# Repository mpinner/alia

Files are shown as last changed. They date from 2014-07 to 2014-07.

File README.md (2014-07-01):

alia
====

Alia: Bringing back human connection (2nd place winner of #ExtremeWearables designathon)

￼￼alia sharing accountability
Mary, Ella, Jon, M, Matt, Divya
￼A pair of socially connected devices
￼‘buddy’
￼Performs interventions to overcome digital addiction
￼￼￼￼￼thinking of having a conversation
￼￼￼
￼Context: Digital Dependency
3 states of being
￼￼￼PLUGGED
UNPLUGGED
ASLEEP
There is tendency of being constantly plugged in.
￼Problem
Addiction to devices (plugged state) is socially acceptable.
Constant connectivity demands an escape i.e a state of being unplugged
Disconnect to physical world affects mental and physical health, personal relationships
￼￼Buddy System
Being accountable to another person is effective in breaking a bad habit
￼￼
alia
￼￼
How it Works
‘Addict’ & ‘Buddy’ relationship
When limit reached, Buddy alerted
Buddy reminds Addict to take break and unplug
￼Device detect loved one’s ‘state level’
How it Works
‘Addict’ & ‘Buddy’ relationship
Device detect loved one’s ‘state level’
Buddy reminds Addict to take break and unplug
￼When limit reached, Buddy alerted
How it Works
‘Addict’ & ‘Buddy’ relationship
￼Buddy reminds Addict to take break and unplug
Device detect loved one’s ‘state level’
When limit reached, Buddy alerted
￼How it Works
Bring back human connection
Each user acts as the buddy and addict at different points
￼￼￼￼￼￼
￼Controls
Hours Limit
￼￼￼Method of Intervention
In person Intervention Intervention by proxy Gentle nudge Annoying tap Electrical Pulse
Fine (money)
￼￼￼￼￼￼￼￼￼￼￼￼￼￼￼￼Strength of Intervension
Mild Intense
￼￼
￼Relationships
Peer to Peer
Friend to Friend
Long Distance Relationships
Couples
Caretaker to Dependant
Parent to Child, Teacher to Student
Between a group of individuals
Group of Friends, Family
￼How it Works
In Touch
Map loved ones and relationsips being tracked to body
Device acts as a portal to connect loved ones and their ‘states’
￼￼￼￼￼￼￼￼￼￼￼
alia
￼￼

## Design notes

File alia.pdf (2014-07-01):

# alia

## sharing accountability

Mary, Ella, Jon, M, Matt, Divya

# A pair of socially connected devices

thinking of | having a conversation
‘buddy’ | Performs interventions to overcome digital addiction

Context: Digital Dependency

PLUGGED | UNPLUGGED | ASLEEP

# 3 states of being

There is tendency of being constantly plugged in.

Problem

Addiction to devices (plugged state) is socially acceptable.

Constant connectivity demands an escape i.e a state of being unplugged

Disconnect to physical world affects mental and physical health, personal relationships

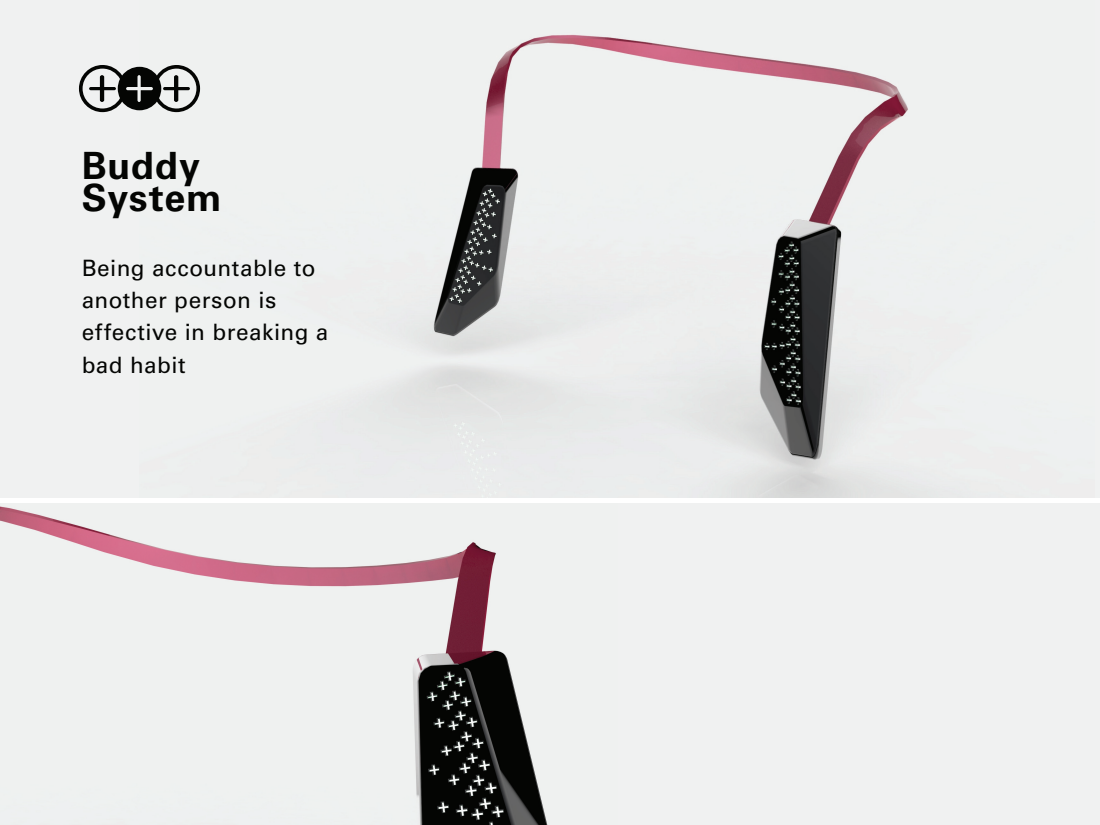
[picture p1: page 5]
Buddy System

Being accountable to
another person is
effective in breaking a
bad habit

# alia

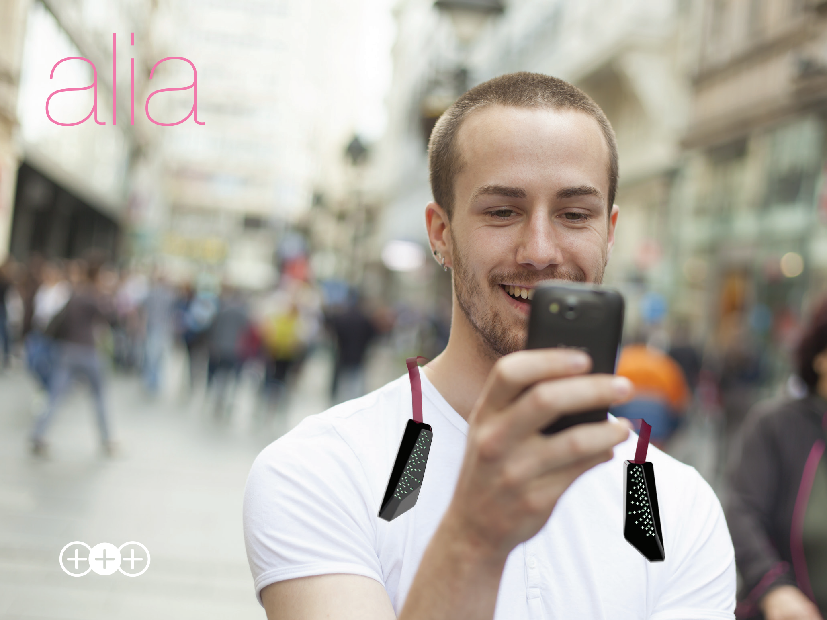
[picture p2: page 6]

# ‘Addict’ & ‘Buddy’ relationship

Device detect
loved one’s
‘state level’

When limit
reached, Buddy
alerted

Buddy reminds
Addict to take
break and
unplug

How it Works

# ‘Addict’ & ‘Buddy’ relationship

Device detect
loved one’s
‘state level’

When limit
reached, Buddy
alerted

Buddy reminds
Addict to take
break and
unplug

How it Works

# ‘Addict’ & ‘Buddy’ relationship

Device detect
loved one’s
‘state level’

When limit
reached, Buddy
alerted

Buddy reminds
Addict to take
break and
unplug

How it Works

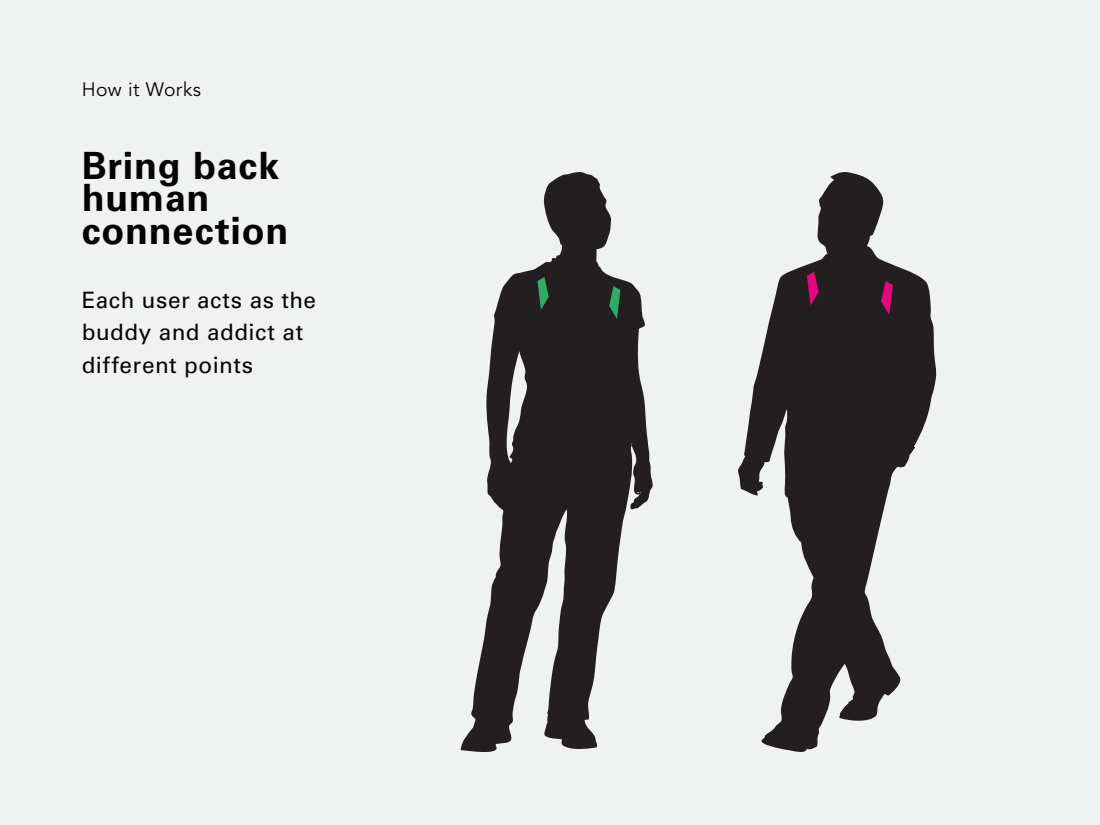
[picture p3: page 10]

How it Works
Bring back
human
connection

Each user acts as the
buddy and addict at
different points

Controls

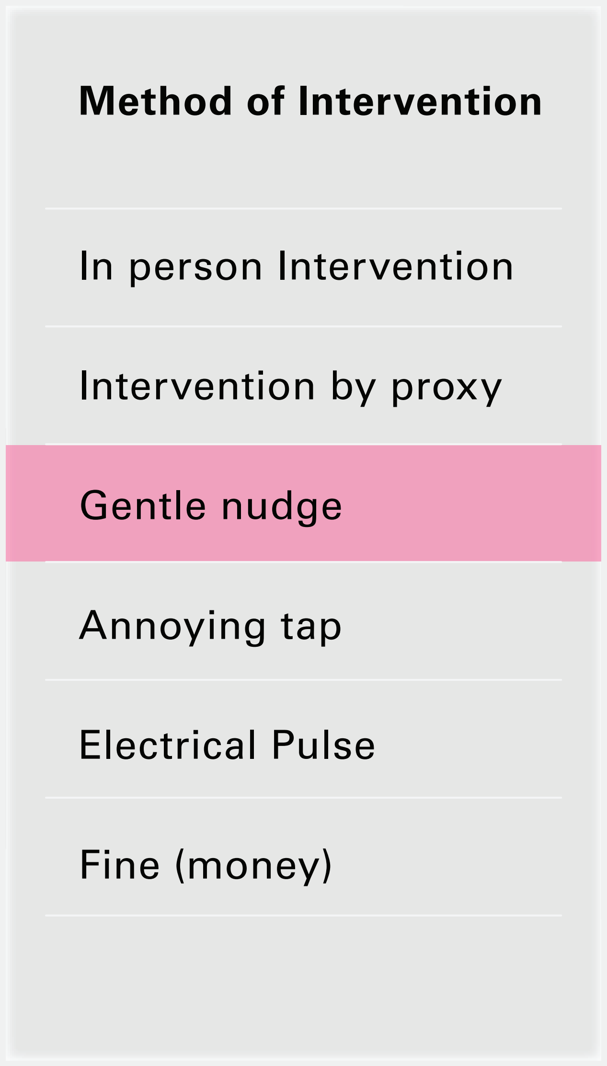
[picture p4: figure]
Method of Intervention; In person Intervention; Intervention by proxy; Gentle nudge; Annoying tap; Electrical Pulse; Fine (money)
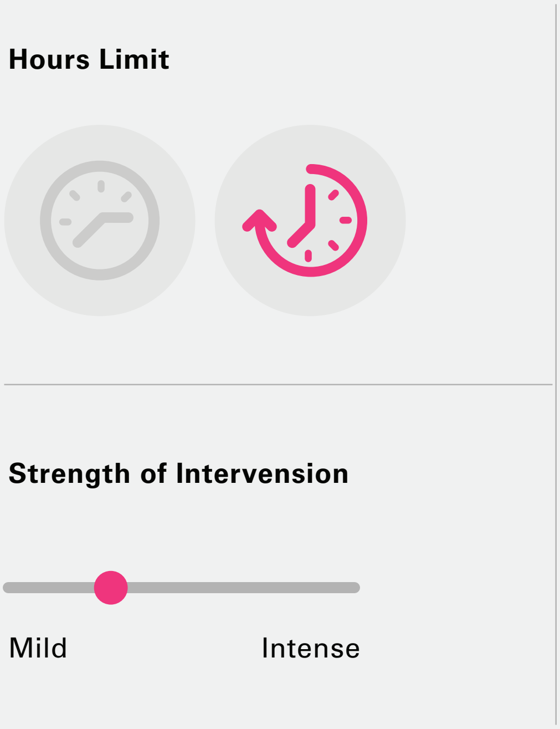
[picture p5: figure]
Hours Limit; Strength of Intervension; Mild; Intense

Relationships

Peer to Peer
Friend to Friend
Long Distance Relationships
Couples
Caretaker to Dependant
Parent to Child, Teacher to Student

Between a group of individuals
Group of Friends, Family

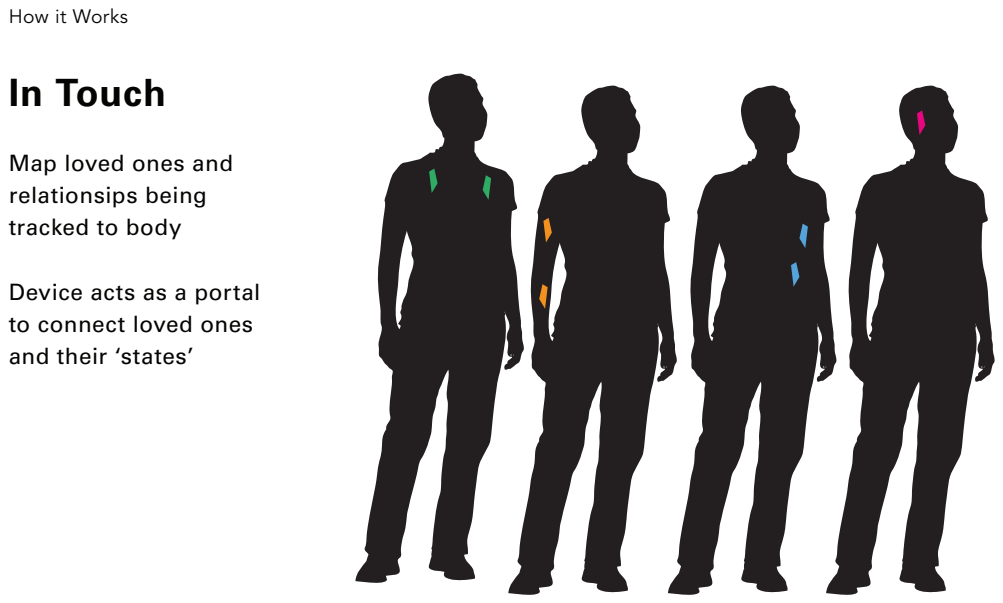
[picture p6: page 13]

How it Works
In Touch

Map loved ones and
relationsips being
tracked to body

Device acts as a portal
to connect loved ones
and their ‘states’

# alia

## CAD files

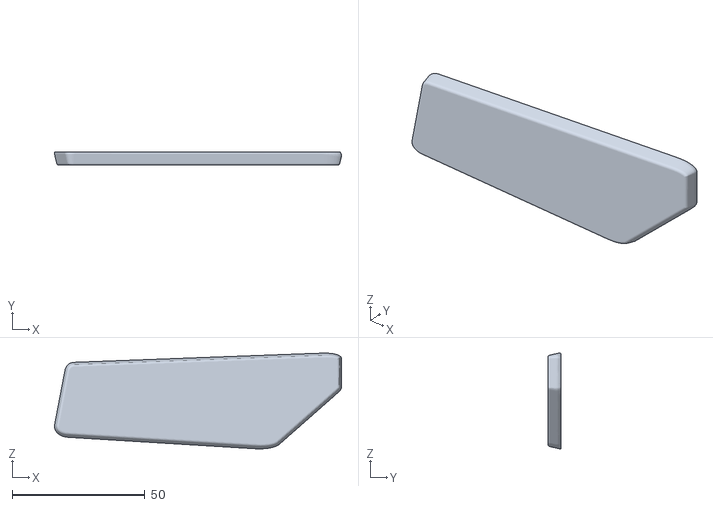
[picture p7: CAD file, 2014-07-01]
models/extreme-wearable-designathon_small-mirrored-bot.STL
108.2 x 5.08 x 36.1

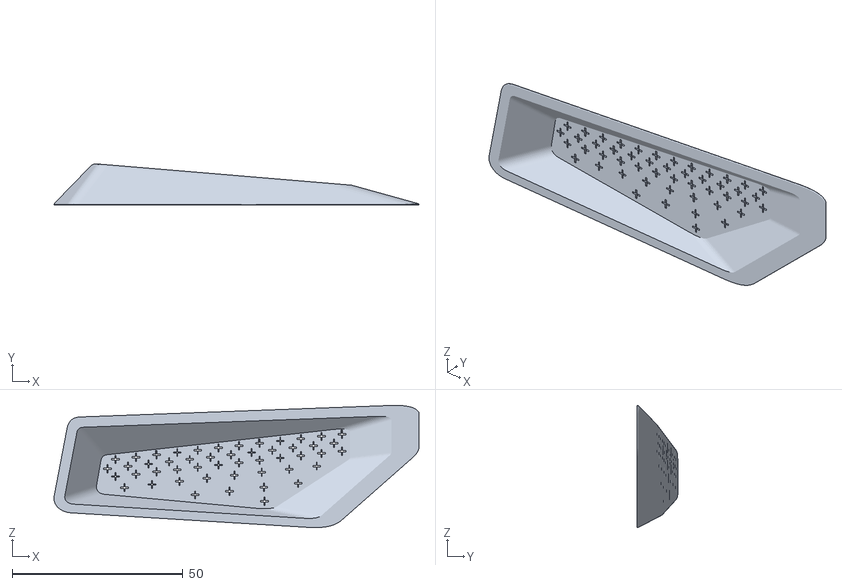
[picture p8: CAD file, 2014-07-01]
models/extreme-wearable-designathon_small-mirrored-top.STL
106.9 x 12.1 x 35.8

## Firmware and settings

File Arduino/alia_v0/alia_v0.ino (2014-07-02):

/* Alia: sharing accountability and bringing back human connection 
 (2nd place winner of #ExtremeWearables designathon)
 Author: matt pinner @mpinner 
 (and team: Ella Jeong, M Asynaps, Jon Hsiung, Mary Kim, Divya Gaitnode)
 
 Intent: connect exactly two people with wearable devices via xbees.
 
 Terms:
 * fuelGauge: shows the sensors readings of the other person's device 
 * emote : recieve a message to the other
 * nudge : send a message to the other
 * sense : read and send local sensors
 * update : send sensor reading
 
 PINS:
 * 0/1 : tx/rx for Serial over XBee 
 * 2   : nudge button (INPUT_PULLUP)
 * 4/5 : adxl345 accelerometer (i2c)
 * 6   : neopixel x8 stick (ws2811)
 * 13  : vibration motor and onboard led (high/low modulated for power savings)
 
 BOM: https://www.sparkfun.com/wish_lists/90529
 * fio: http://arduino.cc/en/Main/ArduinoBoardFio
 * xbee: https://www.sparkfun.com/datasheets/Wireless/Zigbee/XBee-Datasheet.pdf
 * battery: https://www.sparkfun.com/datasheets/Batteries/UnionBattery-1000mAh.pdf 
 * button:https://www.sparkfun.com/datasheets/Components/General/00097.jpg
 * accelerometer: https://www.sparkfun.com/datasheets/Sensors/Accelerometer/ADXL345.pdf
 * leds: https://dlnmh9ip6v2uc.cloudfront.net/datasheets/Components/LED/adafruit-neopixel-uberguide.pdf
 * vibrator: https://www.sparkfun.com/datasheets/Robotics/310-101_datasheet.pdf
 
 PARTS MODELS:
 * fio : https://github.com/sparkfun/3D_Models/tree/master/Products/Prototyping/Arduino%20Fio%20DEV-10116
 * xbee: https://github.com/sparkfun/3D_Models/blob/master/Products/Wireless/XBee%202mW%20PCB%20Antenna%20-%20Series%202%20WRL-11217.skp
 * battery: https://github.com/sparkfun/3D_Models/tree/master/Products/Prototyping/Polymer%20Lithium%20Ion%20Battery%20-%201000mAh%20PRT-00339
 * leds : https://github.com/adafruit/NeoPixel-Sticks | http://www.thingiverse.com/thing:371636
 
 */


#include <Bounce2.h>
#include <Adafruit_NeoPixel.h>

// this NEEDS to be false for anything to work in a P2P mode. 
// this can be on for testing against a Serial monitor
#define DEBUG false

#define BUTTON_PIN 2
#define LEDS_PIN 6
#define VIBE_PIN 13

// We're sending BYTES for our given sensor readings and to nudge
// we save the state of our current reading to send so eventually we can do smoothing
// this defines the initial state for the CONNECTED reading and assumes no data is available
#define INITIALSTATE 49
#define NUDGEMSG 48



// setup the led strip
Adafruit_NeoPixel strip = Adafruit_NeoPixel(16, LEDS_PIN, NEO_GRB + NEO_KHZ800);

// we're currently faking readings for the demo
// we do this by pretending our readings are ever increasing
// this defines how quickly those readings should increase and tracks the last time of increase.
int increaseRate = 30000;
long lastincrease = increaseRate;


// saves the last incoming message from our peer
// 
char inByte = 48;         // incoming serial byte

// tracks our most recently sent data
// ideally this is derived from the current sensor reading with some smoothing
char state = INITIALSTATE;


// Instantiate a Bounce object. this makes using buttons happy.
// not sure this is really needed in this case.
Bounce debouncer = Bounce(); 



// THIS STUFF HAPPENS EXACTLY ONCE UPON INITIAL STARTUP
void setup()
{

  // Setup the button and pull high (hint: this simplifies the electronics)
  pinMode(BUTTON_PIN,INPUT_PULLUP);

  // After setting up the button, setup debouncer
  debouncer.attach(BUTTON_PIN);
  debouncer.interval(5);

  //Setup the VIBRATION MOTOR
  pinMode(VIBE_PIN,OUTPUT);

  // start serial port at 57600 bps and wait for port to open
  // this is also the required baud rate for wireless programming so keep it here
  Serial.begin(57600);
  while (!Serial) {
    ; // wait for serial port to connect. Needed for Leonardo only
  }

  strip.begin();
  strip.show(); // Initialize all pixels to 'off'
  establishContact();  // send a byte to establish contact until receiver responds 
}


// THIS STUFF HAPPENS OVER AND OVER AS FAST AS POSSIBLE
// hint: there is a bit of a delay in the end to avoid over saturating the serial buffers
void loop()
{
  // not used yet...
  //debouncer.update();
  //int value = debouncer.read();


  // Detect user's nudge
  if ( digitalRead(BUTTON_PIN) == HIGH) {
    // button is not pressed, do nothing
  } 
  else {

    // button pressed
    if(DEBUG)  Serial.println("button press");

    // nudge our peer and react locally
    nudge();

  }


  // if we see data from our peer do stuff
  if (Serial.available() > 0) {

    // save incoming byte data
    inByte = Serial.read();

    if(DEBUG) {
      Serial.print(" IN:");
      Serial.println(inByte);
    }

    // if they send us a nudge
    if (NUDGEMSG == inByte) {
      emote();
    } 

    // updates the leds
    update();

  }

  // read and send local sensed data
  sense();


  //avoids over saturating the serial buffers
  delay(250);

  return;
} // END OF loop()


// emote : recieve a nudge from the other
void emote() {

  lightEmUp(8);
  beep(VIBE_PIN,50,145);	
  off();	
  beep(VIBE_PIN,100,145);
  lightEmUp(8);

  beep(VIBE_PIN,200,145);	
  off();	
  beep(VIBE_PIN,400,145);	
  lightEmUp(8);
  beep(VIBE_PIN,800,145);	
  beep(VIBE_PIN,1600,1000);
  off();	

  state=INITIALSTATE;

  return;

}


// nudge our peer and react locally
void nudge() {


  // send peer our nudge 
  Serial.write(NUDGEMSG);

  lightEmUp(8);
  beep(VIBE_PIN,50,500);	
  beep(VIBE_PIN,100,500);	
  off();	


  return;

}


// sense : read and send local sensors
void sense() {
  // send sensor values:
  //if (DEBUG) 
  Serial.write(state);

  if ((millis() - increaseRate) > lastincrease) {
    if(DEBUG) {
      Serial.print(" STATE UPDATE:");
    }
    if (state < (8 + INITIALSTATE)) {
      state++;
      lastincrease = millis();
    }

    if(DEBUG) {
      Serial.println(state);
    }
  }
}


// update: shows the sensors readings of the other person's device 
void update() {

  // calc fuelLevel starting from 1
  int fuelLevel = inByte - NUDGEMSG;

  if (DEBUG) Serial.println("fuel:" + fuelLevel);

  // set all pixels
  for(int i=0; i< 16; i++) {
    strip.setPixelColor(i, 0, 0, 0);

    // turn on lower portion upto fuel level
    if (fuelLevel > i) {
      // pick a nice color
      strip.setPixelColor(i, 30, 50, 60);
    }

  }

  // communicate with pixels
  strip.show();

  return;

}

// make a sound (if speaker or buzzer) or vibration (if motor) or led flash at certain frequency.
// this is nice for power savings and to minimize the current draws
// i was a bit afraid of pulling too much current from my digial pins on the fio during testing with lots of different output devices
void beep (unsigned char speakerPin, int frequencyInHertz, long timeInMilliseconds)     // the sound producing function
{	 
  int x;	 
  long delayAmount = (long)(1000000/frequencyInHertz);
  long loopTime = (long)((timeInMilliseconds*1000)/(delayAmount*2));
  for (x=0;x<loopTime;x++)	 
  {	 
    digitalWrite(speakerPin,HIGH);
    delayMicroseconds(delayAmount);
    digitalWrite(speakerPin,LOW);
    delayMicroseconds(delayAmount);
  }	 
}

// sorta nice to see data upon completion of setup incase your loop is super screwed.
void establishContact() {
  // say hello    
  Serial.write(INITIALSTATE);   // send an initial string

  // not required
  /* while (Serial.available() <= 0) {
   Serial.write(49);   // send an initial string
   delay(500);
   }
   */
}

// util to color all the leds
void lightEmUp (int lights) {

  for(int i=0; i< 16; i++) {
    strip.setPixelColor(i, 0, 0, 0);

    if (lights > i) {
      strip.setPixelColor(i, 180, 200, 255);
    }

  }

  strip.show();
  return;

}



// util to off all the leds
void off (){

  lightEmUp(0);
  return;

}
